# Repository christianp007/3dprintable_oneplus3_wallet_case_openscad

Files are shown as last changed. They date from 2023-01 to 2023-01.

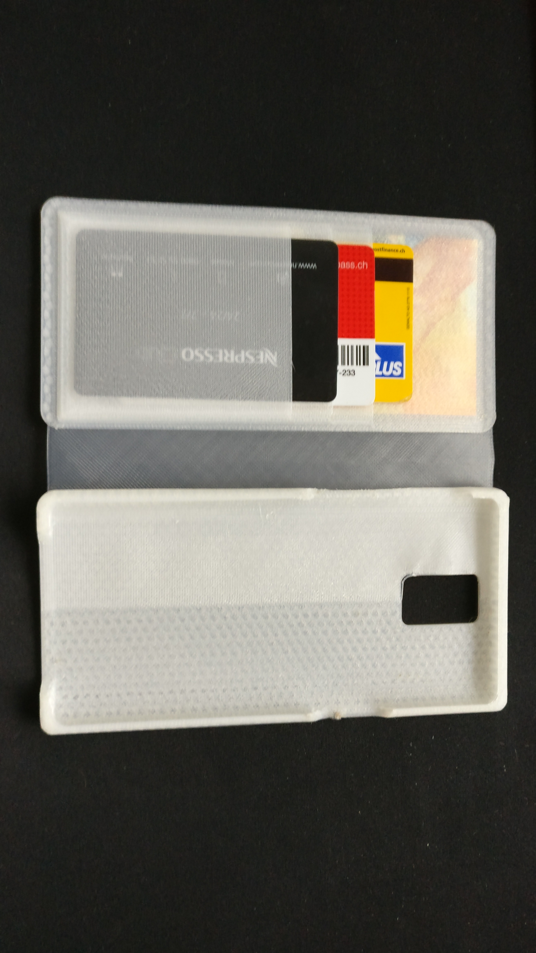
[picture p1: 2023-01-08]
images/onplus3_wallet_case_i1.jpg

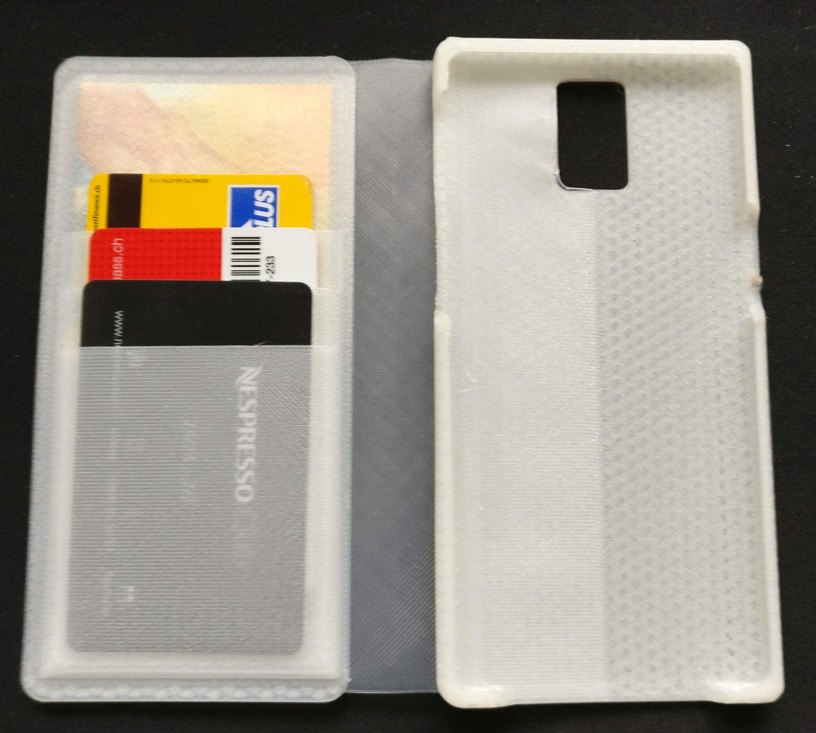
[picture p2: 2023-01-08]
images/onplus3_wallet_case_i1x.jpg

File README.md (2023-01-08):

# 3dprintable_oneplus3_wallet_case_openscad
 A 3d printable customizable wallet case for OnePlus 3/3T designed with OpenSCAD

Customizable types: Wallet Case, Flip Case, Bumper
Customizable text: You can add your own name or signature in customizer, by default its "OnePlus"

Default settings:
Wallet Case with 3 credit card pockets, one extra pocket and an integrated stand.

Images: red case=>Semiflex, transparent=>Taulman PCTPE

We all suffer from bad bed adhision from time to time, why not use it to our advantage?
When adding a small air gap between layers they still adhere during printing but can be seperated to form pockets :-)
I used Simplify3D, not tested with other slicers.

If you have problems separating the layers add a small piece of tape at the air gaps during printing.
Usually its enough to have a 3mm wide opening to insert a screw driver and successively open the pocket.
I used a piece of kapton tape for the stand only, you can see it on the picture (yellow tape).
If you use too much tape the layers may separate during printing which can cause deformation or a failed print.

You should use a flexible material for flip and wallet case styles, as the hinge can break after some time with harder materials.
Optimized for Semiflex/Cheetah, but sucessfully used Taulman PCTPE, too (which is a combination of Nylon and TPE).

Print Settings
Printer:
Kossel XL

Rafts:
No
Supports:
No
Resolution:
0.1
Infill:
30
Notes:
Semiflex/Cheetah
nozzle: 0.4 mm
print width: 0.42 mm
layer height: 0.15 mm
nozzle temp: 240 degrees celsius
bed temp: 50 degrees celsius
speed: 40mm/s
fan on
top/bottom/outline layers: 3/2/2
no raft
infill 30%
outline overlap 10% (use as less as possible)
bridging extrusion multiplier: 100%
bridging speed: 100%

print time: 5:10:00 hours (wallet case)
material used: about 55g

For Taulman PCTPE:
Mostly the same but change following settings:
layerHeight: 0.1
standZLayer: 5
caseSideThickness: 1.9
caseTopBottomThickness: 1.9
phoneDimensionAdditionalX: 0.1
phoneDimensionAdditionalY: 0.1
phoneDimensionAdditionalZ: 0.1

and use these slicer settings:
bed temp: 75 degrees celsius
speed: 75mm/s
fan off
-> print time 2:55:00
-> material used: about 36g

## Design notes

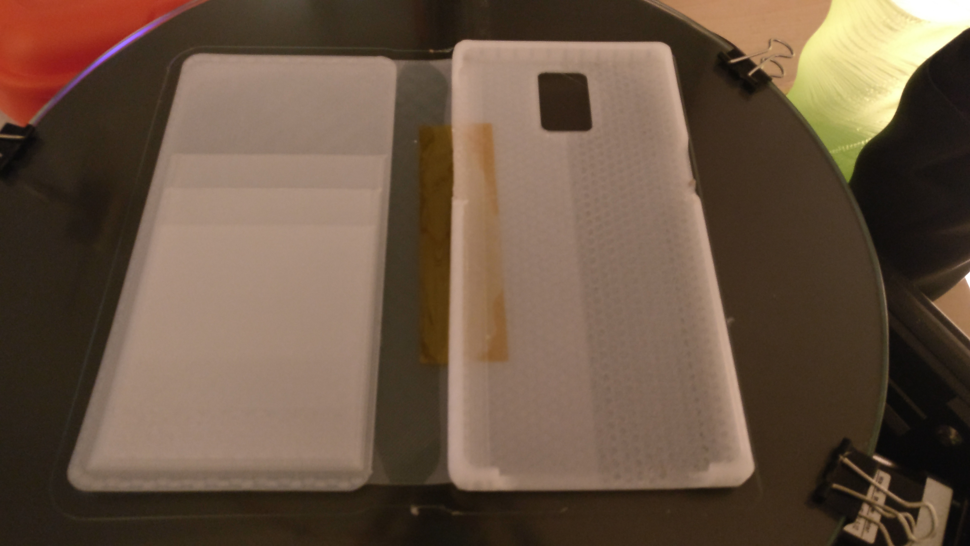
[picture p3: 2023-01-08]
images/onplus3_wallet_case_i2.jpg

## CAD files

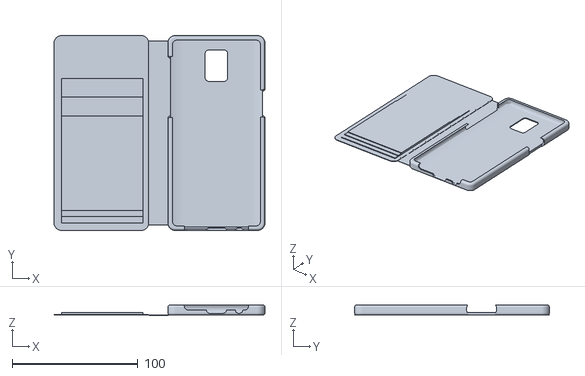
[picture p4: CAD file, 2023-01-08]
op3_case_V4.stl
167.9 x 155.1 x 8.28

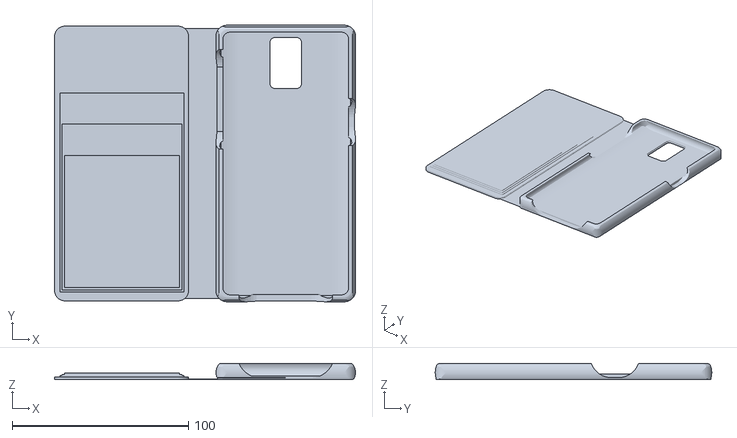
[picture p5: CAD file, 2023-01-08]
oneplus3_wallet_case.stl
170.8 x 156.9 x 9.17

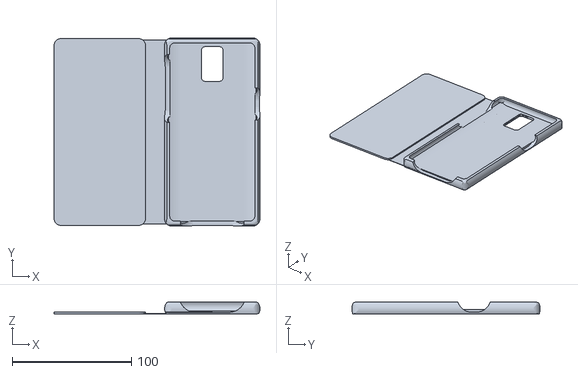
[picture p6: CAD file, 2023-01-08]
oneplus3_wallet_case__flip.stl
172.7 x 157.8 x 9.75

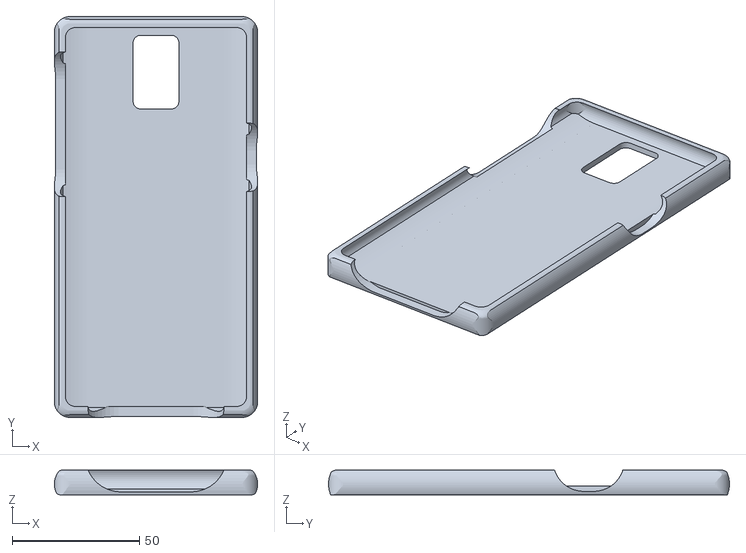
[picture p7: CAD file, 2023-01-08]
oneplus3_wallet_case__bumper.stl
80.0 x 157.8 x 9.75

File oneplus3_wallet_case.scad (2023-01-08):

// Author: Christian Petry
// Designed in Switzerland 2017
// Version: 1.4 (2017-12-12)

/* Version History
V1.0 (2017-11-05) initial version
- optimized for Taulman PCTPE

V1.1 (2017-11-05)
- increased air gap to 2 layers
- number of air gap layers now configurable
- fixed top width not scaling with case wall thickness
- increased cutout Z for left and right cutouts

V1.2 (2017-11-12)
- now optimized for Semiflex (Cheetah)
-- layerHeight 0.1->0.15 and other changes related to using softer material
- slightly increased bottom cutout Z
- top width and hight will now scale only 75% with wall thickness (was 100%)
- increased bottom thickness, so camera is better protected: 1.1 -> 1.8
- slightly decreased hingeXAdditional: 2.0 -> 1.75
- slightly decreased width of credit card pockets
- increased extraYOffsetPerPocket 1.5->2.5
- fixed airgapLayers not working for credit card pockets

V1.3 (2017-11-26)
- Fixed hinge Z was negative, so first layer was hinge only
- some changes to underside thickness and cutouts no longer go all the way down to z=0

V1.4 (2017-12-12)
- added engraved text
- Finetuning
-- standLayer 9 -> 7
-- decreased wall thicknesses for case by 0.3mm
-- reduced topZLayers and extraTopPocketLayer by 1
-- phoneDimensionAdditional X/Y/Z 0.00 -> -0.25
-- case_top_cutoff 0.45 -> 0.48;

V1.5 (2018-01-08)
- Fix: phoneDimensionAdditional Z should not have been set to -0.25, set to 0 again
- phoneDimensionAdditional X/Z -0.25 -> -0.4
- standLayer 7 -> 6
- caseUndersideThickness 2.1 -> 1.8
- posCutout1[2] -1 -> 0

V1.6 (2022-01-08)
- Fix: camera_loc[2] was undefined. Worked fine in old OpenScad version but no longer in current version
*/

/*
Optmized for Semiflex (Cheetah)
For taulman PCTPE change following:
layerHeight: 0.1
standLayer: 5
caseSideThickness: 1.9
caseTopBottomThickness: 1.9
phoneDimensionAdditionalX: 0.1
phoneDimensionAdditionalY: 0.1
phoneDimensionAdditionalZ: 0.1
*/

/* [Main] */
layerHeight=0.15;
caseSideThickness=2.1;
caseTopBottomThickness=2.1;
caseUndersideThickness=1.8;
// position of the stand layer; -1=none
standLayer=6; // [-1:1:20]
// position of the extra pocket layer; 0=none
extraTopPocketLayer=6; // [0:1:20]
// number of credit card pockets; 0=none
numberCreditCardPockets=3; // [0:1:4]
// height of top without credit card pockets; 0=no top, i.e. bumper case
topZLayers=10; // [0:1:20]
// credit card pocket top thickness
creditCardPocketTopLayers=3; // [1:1:5]
// number of layers for air gap
airGapLayers=2; // [1:1:3]
// hinge thickness; 0=none
hingeZLayers=2; // [0:1:20]
// extra space for credit cards and money between phone and top
hingeAdditional=1.75;
// make additional space for phone, use i.e. to offset print precision issues. For very flexible materials you may want to use negative values
phoneDimensionAdditionalX=-0.4;
phoneDimensionAdditionalY=-0.4;
phoneDimensionAdditionalZ=0;

// engraved text
engravedText="OnePlus";
engravedTextLayers=2;
engravedTextSize=8;
engravedTextSpacing=1.2;
engravedTextPosX=-68;
engravedTextPosY=-70;
engravedTextFont="Liberation Sans";

/* [Hidden] */
$fn=50;
phone=[75.2+phoneDimensionAdditionalX,153.0+phoneDimensionAdditionalY,7.8+phoneDimensionAdditionalZ]; // phone dimesions x,y,z

// --- cutouts ---
// volume and alert slider
volumeslider=[45-3,24,30];
posCutout1=[-36.5,-2,-0];
// power button
powerbutton=[15-3,24,30];
posCutout2=[23.5,-2,-1];
// bottom (usb+headphone+speaker)
bottomCutout=[40-3,28,30];
posCutout3=[0,-2,-1.2];
// camera
camera_loc=[0,57,0];
camera=[18,29,20];
camera_rounding=3;

// --- cutoffs ---
case_top_cutoff=0.48;
case_bottom_cutoff=1.7;

// --- phone and case spefific rounding ---
phone_edge=11;
phone_edge_r=37;
rounding=1.7;
s_scale=[3.5,3.5,1];
case_rounding=4;
case_rounding_sphere=2;

// case size offset x,y,z
caseWall=[caseSideThickness, 
caseTopBottomThickness, caseUndersideThickness+case_bottom_cutoff];

hingeX=phone[2]+caseWall[0]+caseWall[2]+hingeAdditional;
hingeWidth=hingeX+hingeAdditional;
hingeZ=hingeZLayers*layerHeight;

topZ=topZLayers*layerHeight;

OVERLAP=0.005;

function creditCardZ()=airGapLayers*layerHeight;

creditCardSpace=[65.4,75]; // x in mm, y in mm
bottomThickness=0;
creditCardPocketSeam=1;
seamTopPocket=1.5;
creditCardPocketTop=layerHeight*creditCardPocketTopLayers;
zOffset=0+creditCardZ()+creditCardPocketTop;
creditCardPocketsStartOffset=2;
creditCardPocketYOffsetPerPocket=19;
creditCardPocketHeight=bottomThickness+creditCardZ()+creditCardPocketTop;
extraYOffsetPerPocket=2.5;


difference(){
    bumper();
    standCutout();
}


if (topZLayers > 0){
    hinge();
    difference(){
        top();
        extraTopPocket();
        translate([0,0,-OVERLAP])
        engravedText();
    }

    if (numberCreditCardPockets > 0){
        translate([0,creditCardPocketsStartOffset,0])
        creditCardPockets();
    }
}

module bumper(){
    translate([0,0,-case_bottom_cutoff])
    difference(){
        difference(){
            resize(newsize=[phone[0]+2*caseWall[0],phone[1]+2*caseWall[1],phone[2]+caseWall[2]])
            phone();
            
            translate([0,0,phone[2]+caseWall[2]+10/2-case_top_cutoff])
            cube([phone[0]*2,phone[1]*2,10], center=true);
            
            translate([0,0,-10/2+case_bottom_cutoff])
            cube([phone[0]*2,phone[1]*2,10], center=true);
        }
        translate([0,0,caseWall[2]])
        union(){
            phone();
            phone_cutouts();
        }
    }
}

module standCutout(){
    sizeFactor=2;
    color([1,0,0])
    translate([-phone[0]/2*sizeFactor,-phone[1]/2*sizeFactor,(standLayer-1)*layerHeight])
    cube([sizeFactor*phone[0]/2,sizeFactor*phone[1],airGapLayers*layerHeight]);
}

module extraTopPocket(){
    zOffset=(airGapLayers*layerHeight)/topZ;
    color([1,0,0])
    scale([1,(phone[1]-2*seamTopPocket)/phone[1],1])
    translate([seamTopPocket,0,(extraTopPocketLayer-1)*layerHeight])
    scale([1,(phone[1]-2*seamTopPocket)/phone[1],zOffset])
    top();
}

module top(){
    scaleSizeWithWallThicknessFactor=0.75;
    translate([-1.5*phone[0]-hingeX+case_rounding-scaleSizeWithWallThicknessFactor*caseWall[0],-phone[1]/2+1.5*case_rounding-scaleSizeWithWallThicknessFactor*caseWall[1],0])
    difference(){
        minkowski(){
            cube([phone[0]-2*1.5*case_rounding-case_rounding_sphere+2*scaleSizeWithWallThicknessFactor*caseWall[0],phone[1]-2*1.5*case_rounding+2*scaleSizeWithWallThicknessFactor*caseWall[1],topZ]);
            cylinder(r=case_rounding*1.5,h=case_rounding);
        }
        translate([-case_rounding*1.5-OVERLAP/2,-case_rounding*1.5-OVERLAP/2,topZ])
        cube([phone[0]+OVERLAP+case_rounding_sphere+caseWall[0],phone[1]+OVERLAP+2*caseWall[1],100]);
    }
}

module creditCardPockets(){    
      translate([-phone[0]-hingeWidth-caseWall[0]/2,-phone[1]/2+creditCardSpace[0]/2+creditCardPocketSeam+case_rounding,topZ])
      {
      for (i=[1:numberCreditCardPockets]){
        creditCardPocket(i,numberCreditCardPockets);
      }
      }
}

module creditCardPocket(pocketNumber,totalNumber){
    yOffset=(totalNumber-pocketNumber)*creditCardPocketYOffsetPerPocket;
    extraYOffset=(totalNumber-pocketNumber)*extraYOffsetPerPocket;
    zOffset=(pocketNumber-1)*creditCardPocketHeight+creditCardPocketHeight/2;
    
    translate([0,yOffset/2+totalNumber/2*extraYOffsetPerPocket-extraYOffset/2,zOffset]){
        cube([creditCardSpace[0]+extraYOffset,creditCardSpace[1]+yOffset,bottomThickness], center=true);
        
        difference(){
            cube([creditCardSpace[0]+extraYOffset,creditCardSpace[1]+yOffset,creditCardPocketHeight], center=true);
            
        translate([0,creditCardPocketSeam+yOffset/2,bottomThickness-(creditCardPocketHeight-creditCardZ())/2])
            cube([creditCardSpace[0]-2*creditCardPocketSeam,creditCardSpace[1]-creditCardPocketSeam,creditCardZ()+OVERLAP], center=true);
        }
    }
}

module hinge(){
    color([1,1,0])
    translate([-phone[0]/2-hingeWidth/2,0,hingeZ/2])
    cube([hingeX+hingeAdditional+2*case_rounding+caseWall[0],phone[1]+2*caseWall[1]-case_rounding,hingeZ], center=true);
}

module phone(){
    translate([-phone[0]/2,phone[1]/2,0])
    rotate([0,0,-90])
	difference()
	{
		intersection()
		{
			translate(
				[rounding*(s_scale[0]),
				rounding*(s_scale[1]),
				0])						
			minkowski()
			{
				cube([phone[1]-2*rounding*s_scale[0],
					phone[0]-2*rounding*s_scale[1],
					phone[2]-rounding*s_scale[2]]);
                
				scale(s_scale)
				difference()
				{
					sphere(rounding);
					translate([-rounding,-rounding,-2*rounding])
					cube(2*rounding);
				}
			}
			
			translate([0,phone[0]/2,phone[2]/2])
				scale([1,1,0.3])
					rotate(90,[0,1,0])
						cylinder(phone[1],d=phone[0], $fn=$fn*3);
		
			translate([phone[1]/2,0,phone[2]/2])
				scale([1,1,0.25])
					rotate(-90,[1,0,0])
						cylinder(phone[0],d=phone[1], $fn=$fn*3);
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

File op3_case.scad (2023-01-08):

use<op3_v2.scad>;

$fn=65;

phone=[153.1, 75.3, 7.8];
op_camera=[25, 18, 5];

phone_height=0.76;
case_thickness=1.4;

case=[4, 4, case_thickness+0.48];
case_rounding=4;
case_rounding_sphere=2;



case_hole_bot_loc=[case[0]+phone[1]/10, 9*phone[1]/10-2*case[0], 7];
case_hole_bot=[1,5];


clearance_phone=phone;
clearance_height=3;
clearance_rounding=0;
s_scale=[1,1,1];

topZ=0.6;

hingeX=phone[2]+1.5;
hingeXAdditional=40;
hingeXOffset=5;
hingeZ=0.3;
//hingeZSeam=0.4;
//hingeZSeamY=1;

OVERLAP=0.01;

x=65;
y=75;
cutoutZ=0.15;
//bottom=0.0;
seam=2;
creditCardHolderTop=0.3;
zOffset=0+cutoutZ+creditCardHolderTop;
creditCardHolderStartOffset=case_rounding;
extraYOffset=3;

rotate([0,0,-90]){        
    difference(){
        union(){
            translate([0,0,-0.01])
            op3_case();

            top();

            hinge();
        }
        translate([0,case_rounding_sphere/2,-1])
    cube([200,0.005,5]);
        translate([0,-hingeX-hingeXOffset-case_rounding*0.5,-1])
    cube([200,0.005,5]);
        translate([18,case_rounding_sphere/2+1.1,-1])
    cube([47.5,0.005,6]);
        translate([phone[0]/2,-hingeX-hingeXOffset,-OVERLAP])
        cube([0.005,hingeX+hingeXOffset,5]);
    }
}

module top(){
    translate([case_rounding*1.5,-phone[1]-hingeX,0])
    difference(){
        minkowski(){
            cube([phone[0]-2*1.5*case_rounding-case_rounding_sphere+case[0],phone[1]-2*1.5*case_rounding+case[0],topZ]);
            cylinder(r=case_rounding*1.5,h=case_rounding);
        }
        translate([-case_rounding*1.5-OVERLAP/2,-case_rounding*1.5-OVERLAP/2,topZ])
        cube([phone[0]+OVERLAP+case_rounding_sphere,phone[1]+OVERLAP+case[0],100]);
    }
    
    color([0.8,0.4,0.4])
    {
//    creditCardHolder(0,30+2*extraYOffset,0,0);
//    creditCardHolder(0,15+extraYOffset,1*zOffset,1);
//    creditCardHolder(0,0,2*zOffset,2);
        
    creditCardHolder(0,15+extraYOffset,0,0);
    creditCardHolder(0,0,1*zOffset,1);
    }  
}

module creditCardHolder(bottomThickness=0,yOffset=0,zOffset=0,number=0){
    translate([phone[0]-y-yOffset-number*extraYOffset-creditCardHolderStartOffset,-phone[1]-hingeX,topZ+zOffset])
    {
        cube([y,x,bottomThickness]);
        difference(){
            cube([y,x,cutoutZ+bottomThickness+creditCardHolderTop]);
            translate([-OVERLAP-15,seam,bottomThickness])
            cube([y-seam+15,x-2*seam,cutoutZ]);
        }
    }
        
    translate([phone[0]-yOffset-number*extraYOffset-creditCardHolderStartOffset,-phone[1]-hingeX,topZ+zOffset])
    cube([yOffset,x,cutoutZ+bottomThickness+creditCardHolderTop]);
}

module hinge(){
    translate([case_rounding_sphere+hingeXOffset/2,-hingeX-hingeXAdditional/2,0])
    {
        cube([phone[0]-case_rounding_sphere-hingeXOffset,hingeX+hingeXAdditional,hingeZ]);
    }
   
}

module op3_case()
{
	difference()
	{		
		translate([case_rounding_sphere, case_rounding_sphere, case_rounding_sphere])
			translate([case_rounding, case_rounding, 0])
			minkowski()
			{
				minkowski()
				{
					cube([ phone[0]+case[0]-2*case_rounding-2*case_rounding_sphere, 
						phone[1]+case[1]-2*case_rounding-2*case_rounding_sphere,
						phone[2]+case[2]-2*case_rounding_sphere-case_thickness]);

					cylinder(0.00001,case_rounding);
				}
				sphere(case_rounding_sphere);
			}


		translate([case[0]/2,case[1]/2,phone_height])
			op3_v2(op_camera);

		// bottom hole
		translate([phone[0]-5,phone[1],case_hole_bot_loc[2]+0.5])
		rotate(-90,[0,0,1])
			rotate(-90,[1,0,0])
				hull()
				{
					translate([case_hole_bot_loc[0]+5,0,0])
						cylinder(case_hole_bot[0]+10, d=case_hole_bot[1]+2);
					
					translate([case_hole_bot_loc[1]-5,0,0])
						cylinder(case_hole_bot[0]+10, d=case_hole_bot[1]+2);
				}

	}
}

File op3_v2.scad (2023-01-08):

$fn=65;

phone=[153.1, 75.3, 7.8];

phone_edge=11;
phone_edge_r=37;

rounding=1.7;
s_scale=[3.5,3.5,1];

camera=[20, 15, 1.5];
camera_rounding=3;
camera_loc=[13+camera[0]/2, phone[1]/2];

			//	POS1 POS2  h   len
volumeslider_loc=[20, 60, 4, 1];
volumeslider=[10, 11];

powerbutton_loc=[47, 59, 4, 1];
powerbutton=[10, 12];

usbport_loc=[phone[1]/2-5, phone[1]/2+5, 3.5, 2];
usbport=[2, 6];

headphone_loc=[phone[1]/2+18, 3.5, 2];
headphone=[2, 6];


op3_v2();

module op3_v2(camera=camera)
{
	difference()
	{
		intersection()
		{
			translate(
				[rounding*(s_scale[0]),
				rounding*(s_scale[1]),
				0])						//*(s_scale[2]) if not halfsphere
			minkowski()
			{
				cube([phone[0]-2*rounding*s_scale[0],
					phone[1]-2*rounding*s_scale[1],
					phone[2]-rounding*s_scale[2]]);	// 2*roundig if not...

				//cylinder(pow(10,-10),r=rounding);
				scale(s_scale)
				difference()
				{
					sphere(rounding);
					translate([-rounding,-rounding,-2*rounding])
					cube(2*rounding);
				}
			}
			
			translate([0,phone[1]/2,phone[2]/2])
				scale([1,1,0.3])
					rotate(90,[0,1,0])
						cylinder(phone[0],d=phone[1], $fn=150);
		
			translate([phone[0]/2,0,phone[2]/2])
				scale([1,1,0.25])
					rotate(-90,[1,0,0])
						cylinder(phone[1],d=phone[0], $fn=150);

		}
		// bottom edge roundings
		for (i = [-1:2:1])
		{
			translate([-1,
				phone_edge*-i+phone[1]*(i/2+0.5),
				phone_edge_r-0.001])
				rotate(90,[0,1,0])
					rotate(-45+i*45,[0,0,1])
						difference()
						{
				cube([phone_edge_r, phone_edge_r, phone[0]+2]);
				cylinder(phone[0]+2,r=phone_edge_r, $fn=150);
						}
		}
	}

	// camera
	translate([camera_loc[0], camera_loc[1], -camera[2]+camera_rounding])
	minkowski()
	{
		cube([camera[0]-2*camera_rounding,
			camera[1]-2*camera_rounding,
			camera[2]], center=true);
		difference()
		{
			sphere(r=camera_rounding);
			translate([-camera_rounding,-camera_rounding,0])
				cube(2*camera_rounding);
		}
	}

	// volume and alert slider
	translate([0,volumeslider_loc[3],volumeslider_loc[2]])
	rotate(90,[1,0,0])
		union()
		{
			hull()
			{
				translate([volumeslider_loc[0],0,0])
					cylinder(volumeslider[0], d=volumeslider[1]);
				
				translate([volumeslider_loc[1],0,0])
					cylinder(volumeslider[0], d=volumeslider[1]);
			}
			// extra cylinder for cleaner look
			difference()
			{
				hull()
				{
					translate([volumeslider_loc[0],0,-volumeslider[0]])
						cylinder(volumeslider[0], d=volumeslider[1]);
					
					translate([volumeslider_loc[1],0,-volumeslider[0]])
						cylinder(volumeslider[0], d=volumeslider[1]);
				}
				translate([0,-volumeslider[1],-volumeslider[0]])
				cube([volumeslider_loc[0]+volumeslider_loc[1],
					volumeslider[1],
					volumeslider[1]]);
			}
			
		}

	// power button
	translate([0,phone[1]-powerbutton_loc[3],powerbutton_loc[2]])
	rotate(-90,[1,0,0])
		union()
		{
			hull()
			{
				translate([powerbutton_loc[0],0,0])
					cylinder(powerbutton[0], d=powerbutton[1]);
				
				translate([powerbutton_loc[1],0,0])
					cylinder(powerbutton[0], d=powerbutton[1]);
			}
			// extra cylinder for cleaner look
			difference()
			{
				hull()
				{
					translate([powerbutton_loc[0],0,-powerbutton[0]])
						cylinder(powerbutton[0], d=powerbutton[1]);
					
					translate([powerbutton_loc[1],0,-powerbutton[0]])
						cylinder(powerbutton[0], d=powerbutton[1]);
				}
				translate([0,0,-powerbutton[0]])
				cube([powerbutton_loc[0]+powerbutton_loc[1],
					powerbutton[1],
					powerbutton[1]]);
			}
			
		}

	// usb port
	translate([phone[0]+usbport_loc[3],0,usbport_loc[2]])
	rotate(90,[0,0,1])
		rotate(-90,[1,0,0])
		union()
		{
			hull()
			{
				translate([usbport_loc[0],0,0])
					union()
					{
						cylinder(usbport[0], d=usbport[1]);
						translate([0,0,usbport[0]])
						sphere(d=usbport[1]);
					}
				
				translate([usbport_loc[1],0,0])
					union()
					{
						cylinder(usbport[0], d=usbport[1]);
						translate([0,0,usbport[0]])
						sphere(d=usbport[1]);
					}
			}
			
		}

	// headphone jack
	translate([phone[0]+headphone_loc[2],0,headphone_loc[1]])
	rotate(90,[0,0,1])
		rotate(-90,[1,0,0])

		translate([headphone_loc[0],0,0])
			union()
			{
				cylinder(headphone[0], d=headphone[1]);
				translate([0,0,headphone[0]])
				sphere(d=headphone[1]);
			}

}

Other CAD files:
test_credit_card_holer.scad
